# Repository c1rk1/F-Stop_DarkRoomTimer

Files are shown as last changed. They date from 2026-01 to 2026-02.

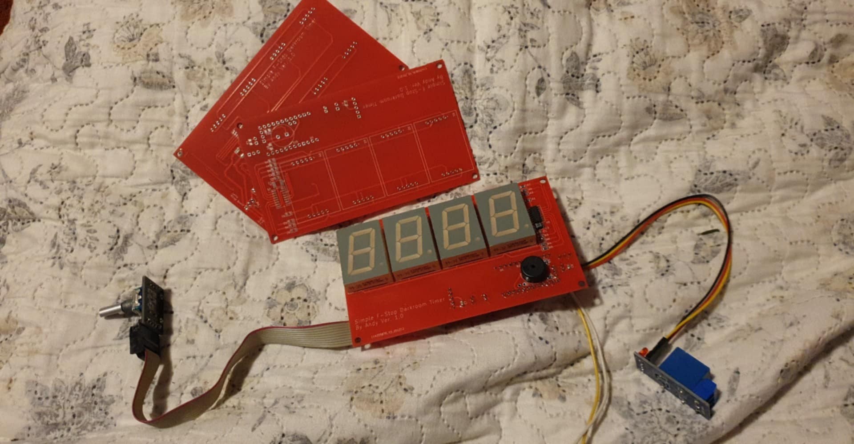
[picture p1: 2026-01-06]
F-Stop_DarkRoomTimer_n.jpg

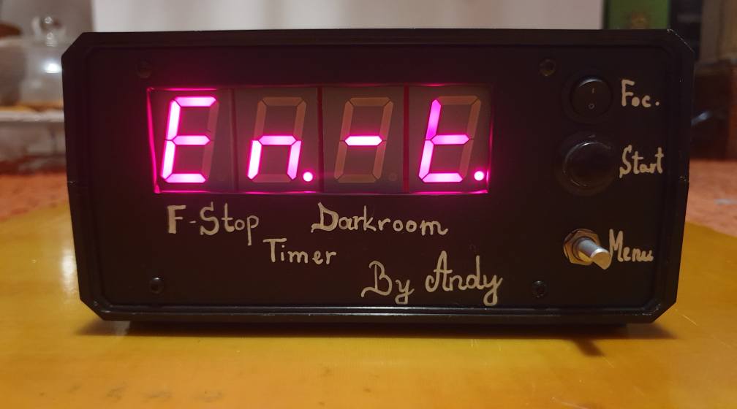
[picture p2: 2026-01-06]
F-Stop_DarkRoomTimer.jpg

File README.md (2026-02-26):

# F-Stop DarkRoom Timer
Simple to build, simple to use "F-Stop" DarkRoom Timer. 
- F-Stop-s  1/1, 1/2, 1/3, 1/4, 1/6, 1/12
- Strip expo feature - 3, 5, 7, 9 strips
- Zone expo feature, from 5 to 15 zones for dodge and burn
- develop timer feature - 1-900sec (15min)

F- stop printing was originally made popular by the award winning printer Gene Nocon in 1987. 

Menu options:
*  En.-t. : Enlarger timer
*  dE.-t. : Develop timer
*  SEt.t. : Set time
*  F-St.  : f-stop set
*  Stri.  : Strip
*  Zone   : Zone expo

En.-t. : Enlarger timer - set the desired value with the rotary encoder (the steps can be set in "F-St." menu) START/Pause with the "Pedal button". Sound will be played on lamp ON and lamp OFF. Default value after power up 10 sec. (you can change it in "SEt.t." menu).

dE.-t. : Develop timer - a simple count down timer in sec. from max 900 to 0 (default after power up 180sec/ 3min) Use rotary encoder to change the value, push long (1sec) to toggle between 1x/10x. Sound will play on begin and end. Start/pause with pedal button.

SEt.t. : Set time - of the enlarger timer start/begining value (0.1-10.0)  default is 10 sec. Use the rotary encoder to change the value, short press to select and go back. This will have effect in "En.-t. : Enlarger timer" menu.

F-St.  : f-stop set - set the steps what you want to use (1/1, 1/2, 1/3, 1/4, 1/6, 1/12 This will have effect in "En.-t. : Enlarger timer" and "Stri.  : Strip" menu

Stri.  : Strip - an easy way to create test strip. First set the estimated exprosure time in "En.-t. : Enlarger timer" menu then in the "Stri.  : Strip" menu select the count of the strips you want (3, 5, 7, 9). It will display ex. "S.-5" from Strip-5. To procced, long press the rotary encoder and the display will show blinking number 1. If you are ready press pedal/START button and exprosure will be made, continue while all strip is done - according to the selected count.
So for example 5. you will have 2 under exprosure and 2 over exprosure and in the middle the estimated value in  "En.-t. : Enlarger timer" menu. Ex: you estimated 10sec in  "En.-t. : Enlarger timer" menu and selected 1/2 F-Stops in "F-St.  : f-stop" menu and S.-5 (five strips). This will be:
1. strip = 5.0sec
2. strip + 2.1sec to previous (total 7.1sec)
3. strip + 2.9sec to previous (total 10.0sec - the middle, what you selected  in  "En.-t. : Enlarger timer" menu)
4. strip + 4.1sec to previous (total 14.1sec)
5. strip + 5.9sec to previous (total 20.0sec)

After developing the paper (use dE.-t. : Develop timer) select the best exprosure time what you can set it in "En.-t. : Enlarger timer" menu.

Zone   : Zone expo is very similar in use to Strip menu but the Zones (sequences) can be select from 5-15. The total expo time will be the time selected in "En.-t. : Enlarger timer" menu and the steps will be F-Stops selected in "F-St.  : f-stop" menu.

Example: you set 20sec in  "En.-t. : Enlarger timer" menu and selected 1/2 F-Stops in "F-St.  : f-stop" menu and Z.-5 (five zone). This will be:
1. Zone = 5.0sec
2. Zone + 2.1sec to previous (total 7.1sec)
3. Zone + 2.9sec to previous (total 10.0sec)
4. Zone + 4.1sec to previous (total 14.1sec)
5. Zone + 5.9sec to previous (total 20.0sec)

The zones will help you to make dodge and burn on the print.

In the schematics I used big 1" 7-segment RED display with the 74HC595 shift registers connected to arduino 5,6,7 pins useing the ShiftDisplay library from Github. You can use any 7segment 4 digit red display what is compatible with the ShiftDisplay library.

Added support for Adafruit_LEDBackpack HT16K33 4 digit 14-Segment Display - use F-Stop_DarkRoomTimer14

* Rotary encoder connect to pins 2,3,4 and GND (A,B, button)
* START/PAUSE pedal/button connect to pin 8 and GND - simple push button or pedal or both
* Lamp controll relay board connect to pin 9 and GND - simple 5v relay board to controll the enlarger
* Piezo buzzer connect to pin 10 and GND on the arduino board.

TO DO list:
1. expand dE.-t. : Develop timer to can select minutes with seconds or seconds only and add selectable tick sound for 10,20,30 sec to use for film developing and tick sound for flip inversion remainder.

Ver. 1.02 
- Added Zone expo feature, from 5 to 15 zones for dodge and burn
  
Ver. 1.01 
- Added 1/4 F-Stop
- Added 0.1 resolution for SEt.t. : Set time menu
- bug fixed when display showed 0.0 instead of 10.0 when e_time variable was 9.9999942

Ver. 1.00 - initial relase

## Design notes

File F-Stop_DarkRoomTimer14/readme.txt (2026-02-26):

For use with Adafruit_LEDBackpack HT16K33 4 digit 14-Segment Display
- just connect to A5 A4 the I2C pins of display and the Vcc and GND to Vcc and GND of arduino.

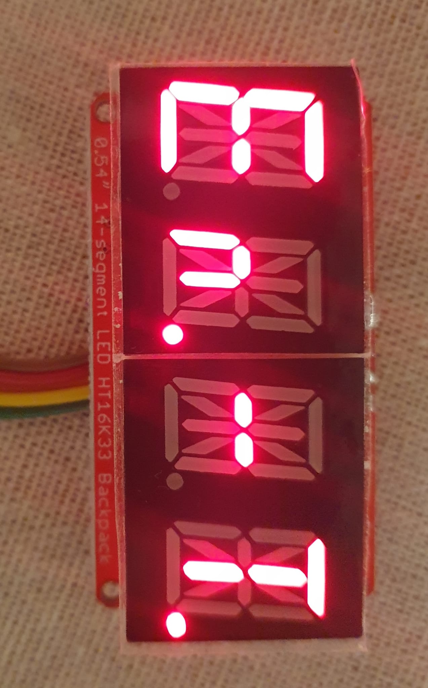
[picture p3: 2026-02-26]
F-Stop_DarkRoomTimer14/HT16K33.jpeg

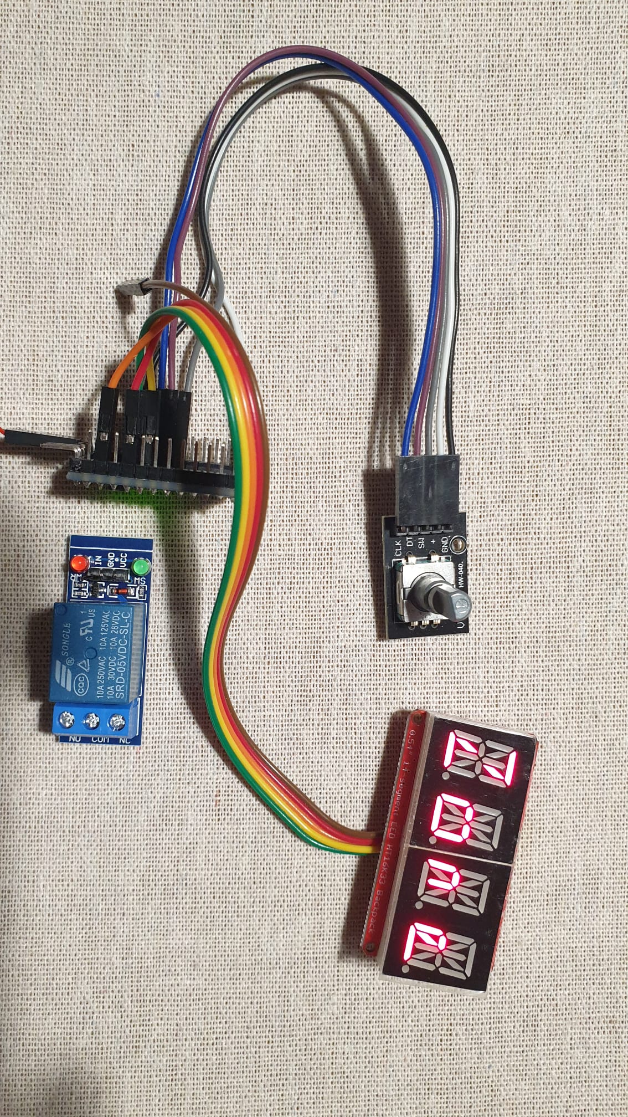
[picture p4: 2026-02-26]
F-Stop_DarkRoomTimer14/HT16K33_.jpeg

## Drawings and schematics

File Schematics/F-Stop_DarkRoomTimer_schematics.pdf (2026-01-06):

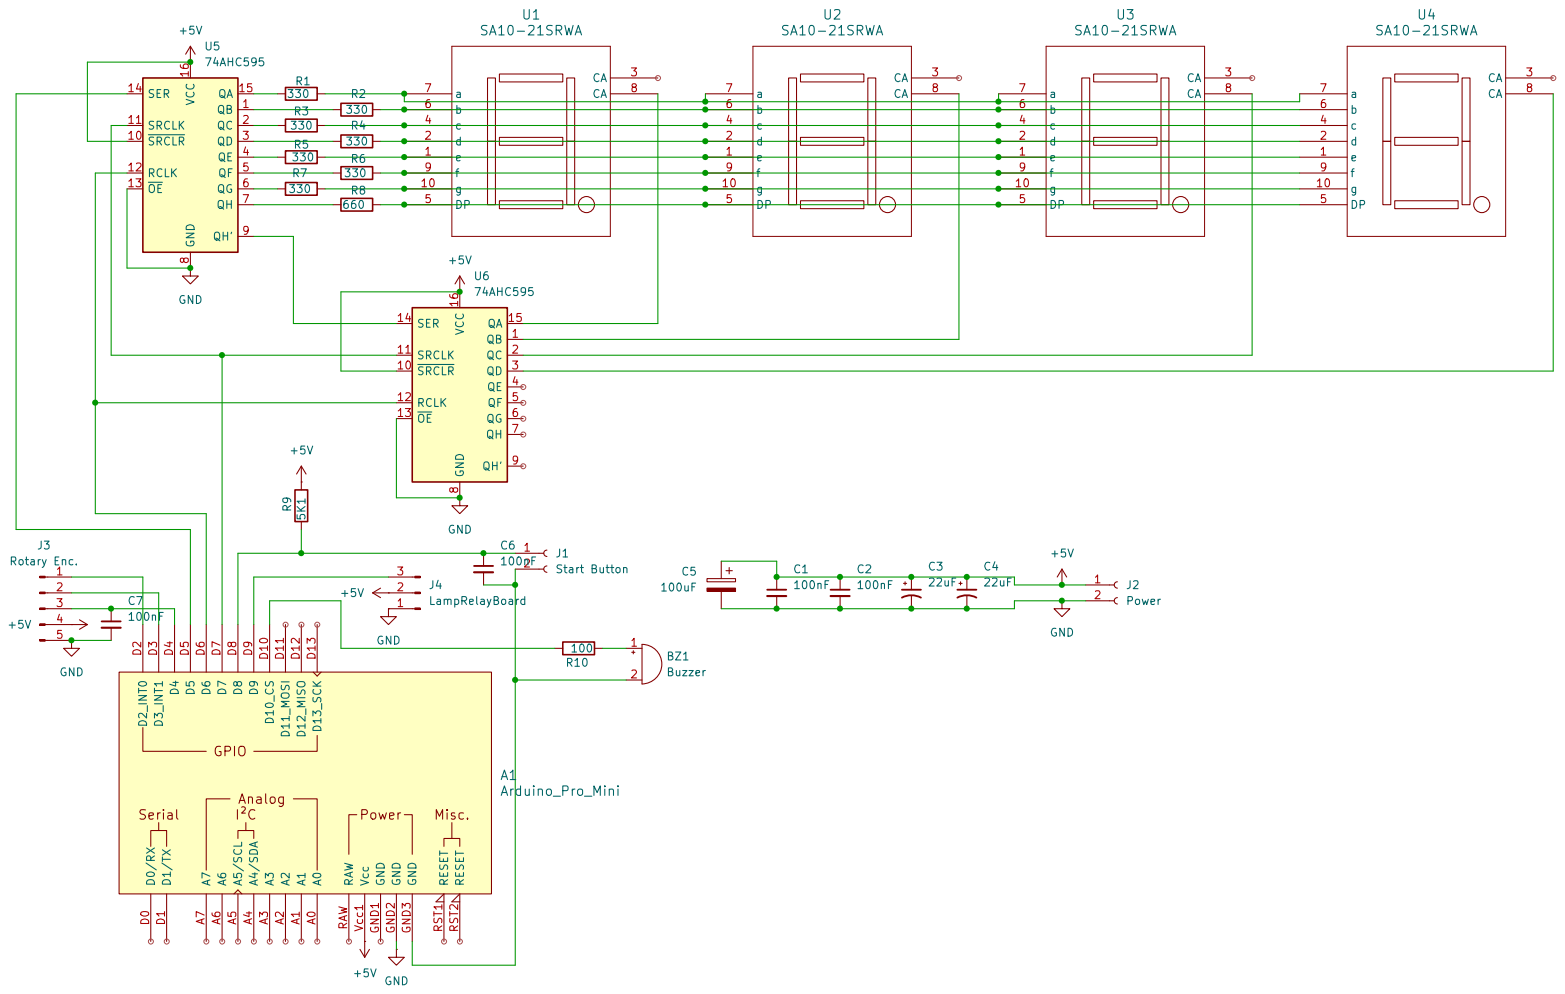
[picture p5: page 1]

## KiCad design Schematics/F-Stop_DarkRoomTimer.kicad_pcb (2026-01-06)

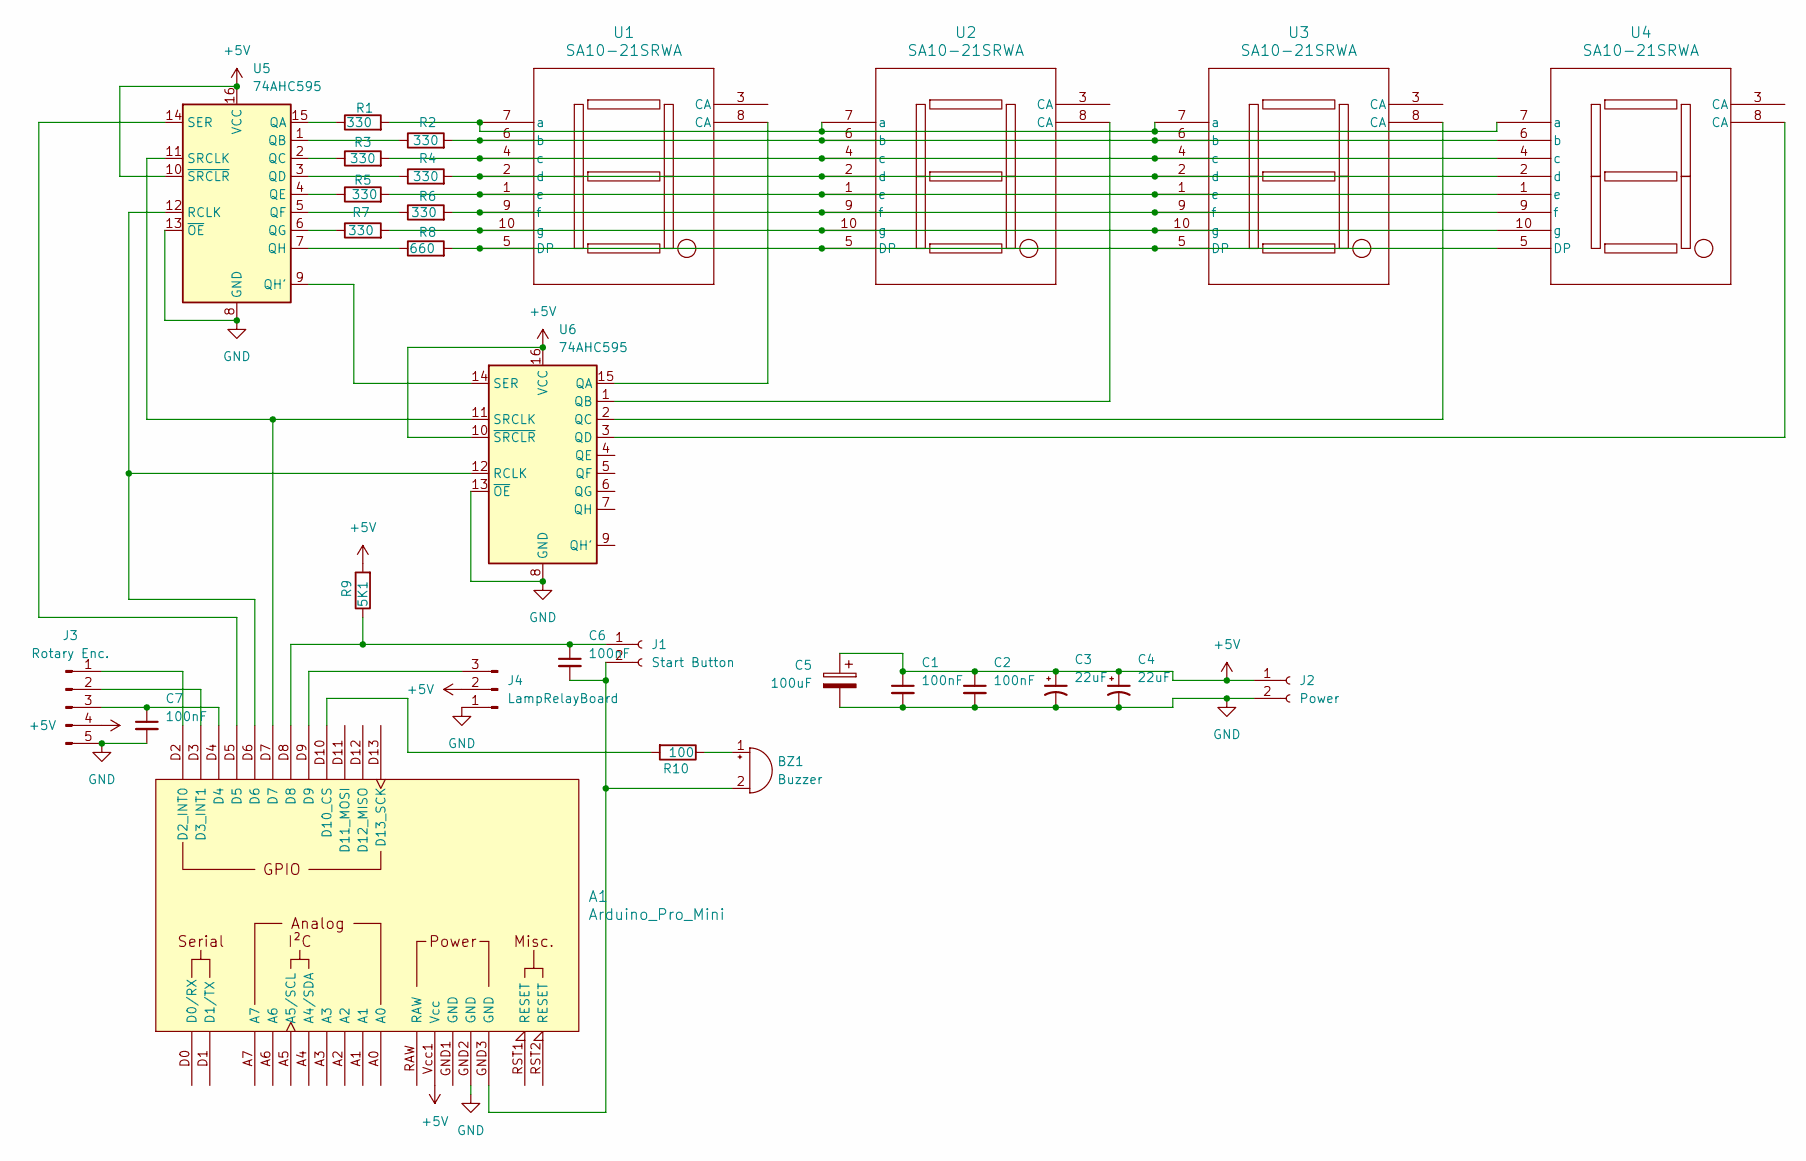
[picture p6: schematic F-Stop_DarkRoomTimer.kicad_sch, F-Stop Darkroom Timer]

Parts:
A1: Arduino_Pro_Mini; Clone_Pro_Mini_Socket_NoSPH
BZ1: Buzzer; Buzzer_TDK_PS1240P02BT_D12.2mm_H6.5mm
C1, C2, C6, C7: 100nF; C_0805_2012Metric_Pad1.18x1.45mm_HandSolder; Voltage 1kV; Tolerance 100%
C3, C4: 22uF; C_1812_4532Metric_Pad1.57x3.40mm_HandSolder; Voltage 1kV; Tolerance 100%
C5: 100uF; CP_Radial_D5.0mm_P2.00mm
J1: Start Button; PinHeader_1x02_P2.54mm_Vertical
J2: Power; PinHeader_1x02_P2.54mm_Vertical
J3: Rotary Enc.; PinHeader_1x05_P2.54mm_Vertical
J4: LampRelayBoard; PinHeader_1x03_P2.54mm_Vertical
R1, R2, R3, R4, R5, R6, R7: 330; R_0805_2012Metric_Pad1.15x1.40mm_HandSolder
R8: 660; R_0805_2012Metric_Pad1.15x1.40mm_HandSolder
R9: 5K1; R_0805_2012Metric_Pad1.15x1.40mm_HandSolder
R10: 100; R_0805_2012Metric_Pad1.15x1.40mm_HandSolder
U1, U2, U3, U4: SA10-21SRWA; SA10-21SRWA_KNB
U5, U6: 74AHC595; SOIC-16_3.9x9.9mm_P1.27mm

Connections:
+5V: A1.Vcc1 (Vcc), C1.1, C2.1, C3.1, C4.1, C5.1, J2.1, J3.4 (Vcc+), J4.2, R9.2, U5.10 (~SRCLR), U5.16 (VCC), U6.10 (~SRCLR), U6.16 (VCC)
GND: A1.GND2 (GND), C1.2, C2.2, C3.2, C4.2, C5.2, C7.2, J2.2, J3.5 (GND), J4.1, U5.8 (GND), U5.13 (~OE), U6.8 (GND), U6.13 (~OE)
unnamed: A1.D2 (D2_INT0), J3.1 (CLK)
unnamed: A1.D3 (D3_INT1), J3.2 (DT)
unnamed: A1.D10 (D10_CS), R10.2
unnamed: BZ1.1 (+), R10.1
unnamed: A1.GND3 (GND), BZ1.2 (-), C6.2, J1.2
unnamed: A1.D8, C6.1, J1.1, R9.1
unnamed: A1.D4, C7.1, J3.3 (SW)
unnamed: A1.D9, J4.3
unnamed: R8.2, U1.5 (DP), U2.5 (DP), U3.5 (DP), U4.5 (DP)
unnamed: R1.2, U1.7 (a), U2.7 (a), U3.7 (a), U4.7 (a)
unnamed: R2.2, U1.6 (b), U2.6 (b), U3.6 (b), U4.6 (b)
unnamed: R3.2, U1.4 (c), U2.4 (c), U3.4 (c), U4.4 (c)
unnamed: R4.2, U1.2 (d), U2.2 (d), U3.2 (d), U4.2 (d)
unnamed: R5.2, U1.1 (e), U2.1 (e), U3.1 (e), U4.1 (e)
unnamed: R6.2, U1.9 (f), U2.9 (f), U3.9 (f), U4.9 (f)
unnamed: R7.2, U1.10 (g), U2.10 (g), U3.10 (g), U4.10 (g)
unnamed: R1.1, U5.15 (QA)
unnamed: R2.1, U5.1 (QB)
unnamed: R3.1, U5.2 (QC)
unnamed: R4.1, U5.3 (QD)
unnamed: R5.1, U5.4 (QE)
unnamed: R6.1, U5.5 (QF)
unnamed: R7.1, U5.6 (QG)
unnamed: U5.9 (QH'), U6.14 (SER)
unnamed: R8.1, U5.7 (QH)
unnamed: A1.D6, U5.12 (RCLK), U6.12 (RCLK)
unnamed: A1.D5, U5.14 (SER)
unnamed: A1.D7, U5.11 (SRCLK), U6.11 (SRCLK)
unnamed: U1.8 (CA), U6.15 (QA)
unnamed: U2.8 (CA), U6.1 (QB)
unnamed: U3.8 (CA), U6.2 (QC)
unnamed: U4.8 (CA), U6.3 (QD)

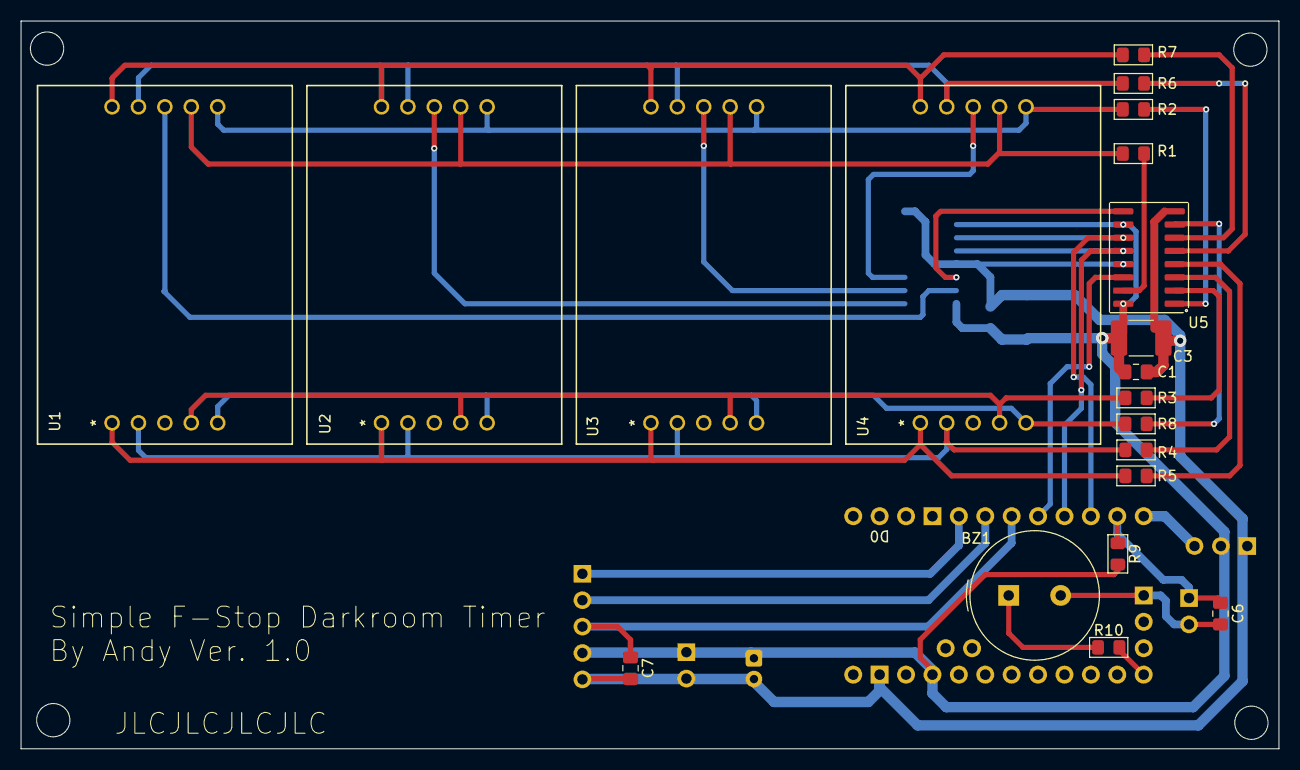
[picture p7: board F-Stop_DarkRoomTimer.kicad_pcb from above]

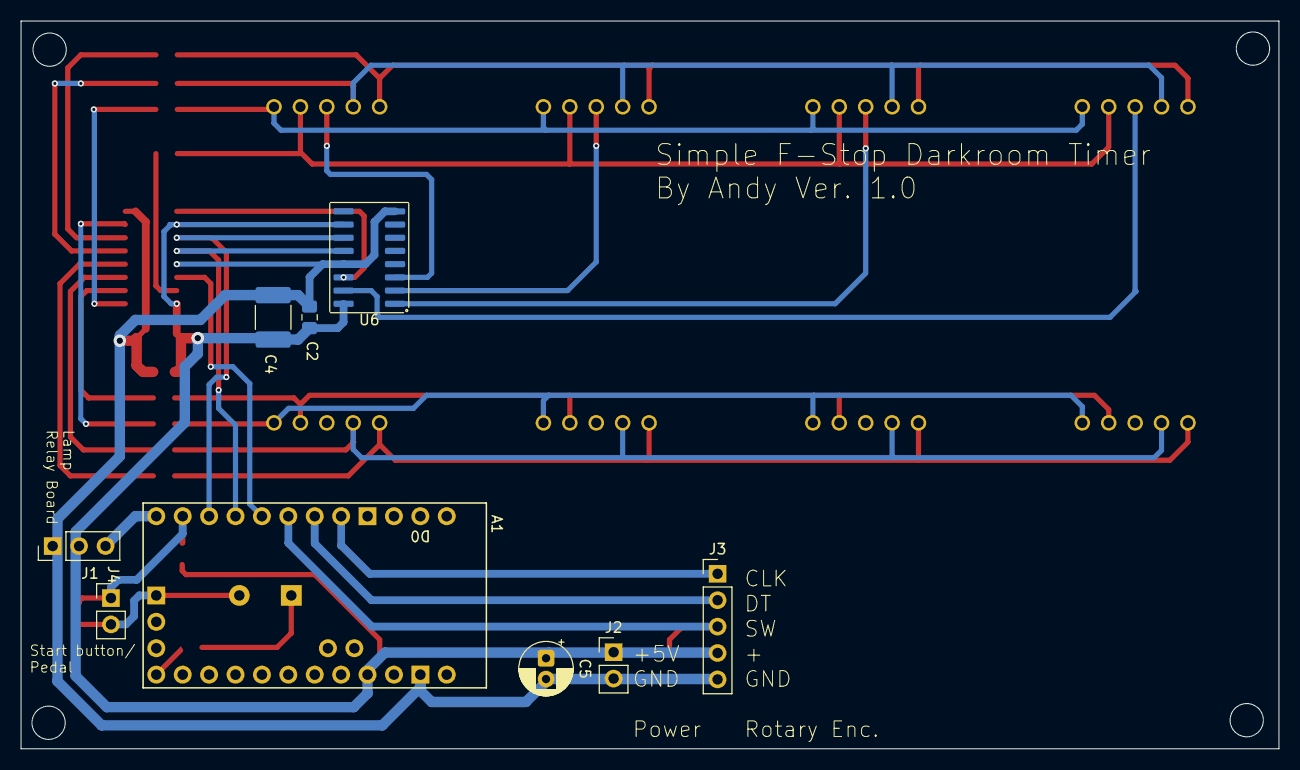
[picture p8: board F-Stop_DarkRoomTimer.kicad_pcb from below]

Board: 2 copper layers, 121.0 x 70.0 mm, 29 parts (9 on the bottom side), 34 nets.

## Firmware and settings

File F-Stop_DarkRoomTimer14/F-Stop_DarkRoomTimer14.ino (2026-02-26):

/*
Simple F-Stop Timer by Andy
- F-Stop of  1/1, 1/2, 1/3, 1/4, 1/6, 1/12
- Strip expo feature - 3, 5, 7, 9 strips
- Zone expo feature from 5 to 15 zones
- develop timer feature - 1-900sec (15min)

Ver. 1.02
2026
*/
#include <SimpleRotary.h>
#include <Button.h>
#include <Wire.h>
#include <Adafruit_GFX.h>
#include <Adafruit_LEDBackpack.h> //HT16K33 4 digit 14-Segment Display

const int ROTA_PIN = 2;       // rotary encoder A pin
const int ROTB_PIN = 3;       // rotary encoder B pin
const int ROTBUTTON_PIN = 4;  // rotary encoder button pin
const int SBUTTON_PIN = 8;    // START button/pedal pin
const int LAMP_PIN = 9;       //Lamp relay pin
const int BUZZER_PIN = 10;    // buzzer pin
const int t0ne = 523;         //buzzer tome
const int TOP = 1;            // top of menu
                              //menu order
const int EN_T = 1;           // Enlarger timer menu
const int STRI = 2;           // Strip menu
const int ZONE = 3;           // Zone menu
const int DE_T = 4;           // Develop timer menu
const int SETT = 5;           // Set initial time menu
const int F_ST = 6;           // Set F-Stop-s menu

const int MAXM = 6;  // max  menu item

Adafruit_AlphaNum4 display = Adafruit_AlphaNum4();

byte encdir, encbut, menulevel, menuitem, itemcount, f_stop, strip;
float e_time, d_time, countdown, temp_time;
byte f_stop_[7] = { 0, 1, 2, 3, 4, 6, 12 };  // 1/1, 1/2, 1/3, 1/4, 1/6, 1/12
byte strip_[5] = { 0, 3, 5, 7, 9 };          //strip count -/0/+ with f-stop step
String temp_str;
bool _10x;
float strip_expo_[20];  //store strip / zone values


SimpleRotary rotary(ROTA_PIN, ROTB_PIN, ROTBUTTON_PIN);  // Rotary Encoder Pin A, Pin B, Button Pin
Button pedal(SBUTTON_PIN);


void setup() {
  display.begin(0x70);  // pass in the address
  display.clear();
  display.writeDisplay();
 // Serial.begin(115200);                   // for debug
  displayshow("1.02", 1000, &display);  //show version
  rotary.setTrigger(HIGH);              // Set the trigger to be either a HIGH or LOW pin (Default: HIGH) Note this sets all three pins to use the same state.
  rotary.setDebounceDelay(5);           // Set the debounce delay in ms  (Default: 2)
  rotary.setErrorDelay(250);            // Set the error correction delay in ms  (Default: 200)
  pedal.begin();
  // pinMode(SBUTTON_PIN, INPUT);
  pinMode(BUZZER_PIN, OUTPUT);
  pinMode(LAMP_PIN, OUTPUT);
  digitalWrite(LAMP_PIN, HIGH);  //turn OFF

  menulevel = TOP;
  menuitem = 1;      // start with first
  itemcount = MAXM;  // menu items
  f_stop = f_stop_[3];
  strip = strip_[3];
  e_time = 10.0;  // default 10 sec.
  d_time = 180;   // 180 sec - 3min for average paper
}

void loop() {
  encbut = rotary.pushType(1000);
  encdir = rotary.rotate();
  switch (encdir) {
    case 1:
      menuitem = menuitem + 1;
      if (menuitem > itemcount)
        menuitem = 1;
      break;
    case 2:
      menuitem = menuitem - 1;
      if (menuitem < 1)
        menuitem = itemcount;
      break;
  }
  if (menulevel == 1) {
    switch (menuitem) {
      case F_ST:  //set F-STOPs steps
        displayset("F-St.", &display);
        if (encbut == 1) {
          menulevel = 11;
          encbut = 0;
          itemcount = 6;                                //count of values in array
          menuitem = binarySearch(f_stop_, 7, f_stop);  //find selected value in array
        }
        break;
      case STRI:  //set strip count
        displayset("STRI.", &display);
        if (encbut == 1) {
          menulevel = 21;
          encbut = 0;
          itemcount = 4;                              //count of values in array
          menuitem = binarySearch(strip_, 5, strip);  //find selected value in array
        }
        break;
      case EN_T:  // enlarger timer
        displayset("En.-T.", &display);
        if (encbut == 1) {
          menulevel = 31;
          encbut = 0;
          encdir = 0;
        }
        break;
      case DE_T:  //develop timer
        displayset("De.-T.", &display);
        if (encbut == 1) {
          menulevel = 41;
          encbut = 0;
          _10x = true;
        }
        break;
      case SETT:  //Set initial time
        displayset("Set.T", &display);
        if (encbut == 1) {
          menulevel = 51;
          encbut = 0;
          itemcount = 100;
          menuitem = 100;
        }
        break;
      case ZONE:  // Zone fuction
        displayset("Zone", &display);
        if (encbut == 1) {
          menulevel = 61;
          encbut = 0;
          itemcount = 15;
          menuitem = 5;
        }
        break;
    }
  }
  if (menulevel == 11) {  //set F-STOPs steps
    temp_str = "1-" + String(f_stop);
    displayset(temp_str.c_str(), &display);
    f_stop = f_stop_[menuitem];
    if (encbut == 1) {  //return
      menulevel = TOP;
      menuitem = F_ST;
      itemcount = MAXM;
    }
  }

  if (menulevel == 21) {  //set strip count
    temp_str = "S.-" + String(strip);
    displayset(temp_str.c_str(), &display);
    strip = strip_[menuitem];
    if (encbut == 2)
      strip_expo();
    if (encbut == 1) {
      menulevel = TOP;
      menuitem = STRI;
      itemcount = MAXM;
    }
  }

  if (menulevel == 31) {  // enlarger timer
    switch (encdir) {
      float temp_time;
      case 1:
        temp_time = e_time;
        e_time = e_time * pow(2.0, 1.0 / f_stop);
        if (e_time > 999)
          e_time = temp_time;
        break;
      case 2:
        temp_time = e_time;
        e_time = e_time * pow(2.0, -1.0 / f_stop);
        if (e_time < 0.1)
          e_time = temp_time;
        break;
    }
    if (encdir != 0)
      countdown = 0;

    if (pedal.pressed())
      expo();
    if (countdown == 0) {
      temp_str = String(e_time, 1);
      displayset(temp_str.c_str(), &display);
    } else {
      temp_str = String(countdown, 1);
      displayset(temp_str.c_str(), &display);
    }
    if (encbut == 1) {
      menulevel = TOP;
      menuitem = EN_T;
      countdown = 0;
    }
  }

  if (menulevel == 41) {  //develop timer
    switch (encdir) {
      case 1:
        if (_10x)
          d_time = d_time + 10;
        else
          d_time = d_time + 1;
        if (d_time > 900)
          d_time = 1;
        break;
      case 2:
        if (_10x)
          d_time = d_time - 10;
        else
          d_time = d_time - 1;
        if (d_time < 1)
          d_time = 900;
        break;
    }
    temp_str = String(d_time, 1);
    displayset(temp_str.c_str(), &display);
    if (encdir != 0)
      countdown = 0;

    if (encbut == 2)
      if (_10x) {
        _10x = false;
        displayshow("+1.0", 500, &display);
      } else {
        _10x = true;
        displayshow("+10.0", 500, &display);
      }

    if (pedal.pressed())
      develop_timer();
    if (countdown == 0) {
      temp_str = String(d_time, 1);
      displayset(temp_str.c_str(), &display);
    } else {
      temp_str = String(countdown, 1);
      displayset(temp_str.c_str(), &display);
    }
    if (encbut == 1) {
      menulevel = TOP;
      menuitem = DE_T;
      countdown = 0;
    }
  }

  if (menulevel == 51) {  //Set initial time
    temp_str = String(e_time, 1);
    displayset(temp_str.c_str(), &display);
    if (encdir != 0)
      e_time = menuitem / 10.0;
    if (encbut == 1) {
      menulevel = TOP;
      menuitem = SETT;
      itemcount = MAXM;
    }
  }
  if (menulevel == 61) {  // Zone fuction
    if (menuitem == 4)
      menuitem = 15;
    if (menuitem == 1)
      menuitem = 5;
    temp_str = "Z.-" + String(menuitem);
    displayset(temp_str.c_str(), &display);
    if (encbut == 2)
      zone_expo();
    if (encbut == 1) {
      menulevel = TOP;
      menuitem = ZONE;
      itemcount = MAXM;
    }
  }
  display.writeDisplay();
}


void strip_expo() {  //strip expo
  encbut = 0;
  byte s = strip / 2;
  strip_expo_[s] = e_time;
  byte i = s;
  while (i != 0) {
    i--;
    strip_expo_[i] = strip_expo_[i + 1] * pow(2.0, -1.0 / f_stop);
  }
  i = s + 1;
  while (i < strip) {
    strip_expo_[i] = strip_expo_[i - 1] * pow(2.0, 1.0 / f_stop);
    i++;
  }
  /*for (i = 0; i < strip; i++)
    Serial.println(strip_expo_[i]);   //*/
  s = 1;
  while (s <= strip && rotary.pushType(1000) != 1) {

    temp_str = "S.-" + String(s);
    displayshow(temp_str.c_str(), 250, &display);
    displayshow("S.-", 250, &display);
    if (pedal.pressed()) {
      if (countdown == 0)
        if (s == 1)
          countdown = strip_expo_[s - 1];
        else
          countdown = strip_expo_[s - 1] - strip_expo_[s - 2];
      lamp_on(true);
      tone(BUZZER_PIN, t0ne, 500);
      while (!pedal.pressed() && (countdown != 0)) {
        temp_str = String(countdown, 1);
        displayshow(temp_str.c_str(), 100, &display);  // float with one decimal place, display 100ms
        countdown = countdown - 0.1;
        if (countdown < 0) {
          countdown = 0;
          s = s + 1;
        }
      }
      lamp_on(false);
      tone(BUZZER_PIN, t0ne, 500);
    }
  }
  countdown = 0;
}

void expo() {
  if (countdown == 0)
    countdown = e_time;
  lamp_on(true);
  tone(BUZZER_PIN, t0ne, 500);

  while (!pedal.pressed() && (countdown != 0)) {
    temp_str = String(countdown, 1);
    displayshow(temp_str.c_str(), 100, &display);  // float with one decimal place, display 100ms
    countdown = countdown - 0.1;
    if (countdown < 0)
      countdown = 0;
  }
  lamp_on(false);
  tone(BUZZER_PIN, t0ne, 500);
}

void develop_timer() {
  if (countdown == 0)
    countdown = d_time;
  tone(BUZZER_PIN, t0ne, 500);

  while (!pedal.pressed() && (countdown != 0)) {
    temp_str = String(countdown, 1);
    displayshow(temp_str.c_str(), 100, &display);  // float with one decimal place, display 100ms
    countdown = countdown - 0.1;
    if (countdown < 0)
      countdown = 0;
  }
  tone(BUZZER_PIN, t0ne, 500);
}

void zone_expo() {  //zone expo
  encbut = 0;
  byte s = menuitem - 1;
  strip_expo_[s] = e_time;
  while (s != 0) {  // load expo values
    s--;
    strip_expo_[s] = strip_expo_[s + 1] * pow(2.0, -1.0 / f_stop);
  }
  /*
  for (s = 0; s < menuitem; s++)
    Serial.println(strip_expo_[s]);  //*/
  s = 1;
  while (s <= menuitem && rotary.pushType(1000) != 1) {

    temp_str = "Z.-" + String(s);
    displayshow(temp_str.c_str(), 250, &display);
    displayshow("Z.-", 250, &display);
    if (pedal.pressed()) {
      if (countdown == 0)
        if (s == 1)
          countdown = strip_expo_[s - 1];
        else
          countdown = strip_expo_[s - 1] - strip_expo_[s - 2];
      lamp_on(true);
      tone(BUZZER_PIN, t0ne, 500);
      while (!pedal.pressed() && (countdown != 0)) {
        temp_str = String(countdown, 1);
        displayshow(temp_str.c_str(), 100, &display);  // float with one decimal place, display 100ms
        countdown = countdown - 0.1;
        if (countdown < 0) {
          countdown = 0;
          s = s + 1;
        }
      }
      lamp_on(false);
      tone(BUZZER_PIN, t0ne, 500);
    }
  }
  countdown = 0;
}

void lamp_on(bool turnon) {

  if (turnon)
    digitalWrite(LAMP_PIN, LOW);
  else
    digitalWrite(LAMP_PIN, HIGH);
}

byte binarySearch(byte array[], byte size, byte target) {
  int left = 0;
  int right = size - 1;

  while (left <= right) {
    int mid = left + (right - left) / 2;

    // Check if target is at mid
    if (array[mid] == target) {
      return mid;
    }

    // If target is greater, ignore left half
    if (array[mid] < target) {
      left = mid + 1;
    }
    // If target is smaller, ignore right half
    else {
      right = mid - 1;
    }
  }
  // Target is not present in array
  return -1;
}

void displayshow(char* str, int _delay, Adafruit_AlphaNum4* alphanum) {
  display.clear();
  int j = 0;
  if (str[0] >= '0' && str[0] <= '9')  //align right
  {
    j = strlen(str) - 1;
    for (int i = 3; i >= 0; i--) {
      if ('.' == str[j])  //if the next character after this one is '.'
      {
        j--;
        alphanum->writeDigitAscii(i, str[j], true);  //write the '.' along with the character
                                                         //skip over the '.'
      } else {
        alphanum->writeDigitAscii(i, str[j]);  //write the character
      }
      j--;
      if (j < 0)
        break;
    }
  } else
  for (int i = 0; i < 4; i++)  //for each digit
  {
    if (str[j] == 0)
      break;
    if ('.' == str[j + 1])  //if the next character after this one is '.'
    {
      alphanum->writeDigitAscii(i, str[j], true);  //write the '.' along with the character
      j++;                                         //skip over the '.'
    } else {
      alphanum->writeDigitAscii(i, str[j]);  //write the character
    }
    j++;
  }
  alphanum->writeDisplay();  //write to the display.
  delay(_delay);
}

void displayset(char* str, Adafruit_AlphaNum4* alphanum) {
  display.clear();
  int j = 0;
  if (str[0] >= '0' && str[0] <= '9')  //align right
  {
    j = strlen(str) - 1;
    for (int i = 3; i >= 0; i--) {
      if ('.' == str[j])  //if the next character after this one is '.'
      {
        j--;
        alphanum->writeDigitAscii(i, str[j], true);  //write the '.' along with the character
                                                         //skip over the '.'
      } else {
        alphanum->writeDigitAscii(i, str[j]);  //write the character
      }
      j--;
      if (j < 0)
        break;
    }
  } else //* / 
  for (int i = 0; i < 4; i++)  //for each character in str
  {
      if (str[j] == 0)
        break;
      if ('.' == str[j + 1])  //if the next character after this one is '.'
      {
        alphanum->writeDigitAscii(i, str[j], true);  //write the '.' along with the character
        j++;                                         //skip over the '.'
      } else {
        alphanum->writeDigitAscii(i, str[j]);  //write the character
      }
      j++;
    }
}
